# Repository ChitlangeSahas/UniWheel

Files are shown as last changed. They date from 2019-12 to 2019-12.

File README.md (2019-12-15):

# UniWheel - A DIY self balancing mobility vehicle

<p>
             
 </p>
<br>
<br>

*I built this project over 9 month time period, going from the ideation to the prototype.*

### Contains: 
* NodeMCU Controller Code (__C++__) 
* Android App Code repository (__Java__) : [link to the repository](https://github.com/ChitlangeSahas/UniWheel-Android-App) 
* CAD Files Inventor (__Inventor Professional 2019__)

### Media :
 * Video in action : [Watch Video](https://bit.ly/sahas-uniwheel)
 * CAD Render Model : 
 
    <p align="center">
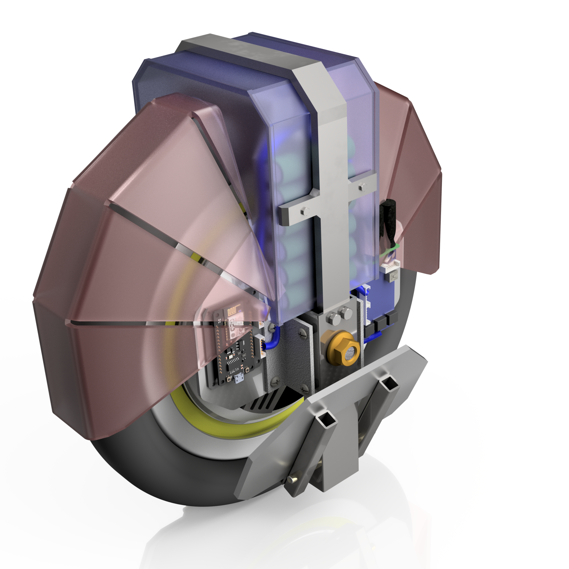
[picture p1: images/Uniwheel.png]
      
      </p>
 
### Some favorite captures :
<p align="center">
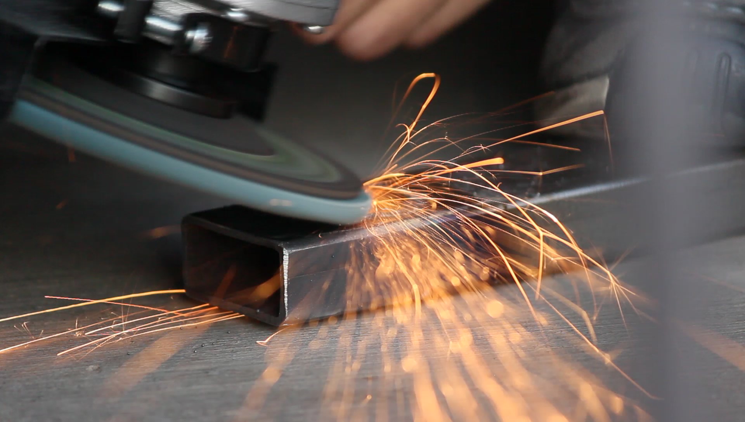
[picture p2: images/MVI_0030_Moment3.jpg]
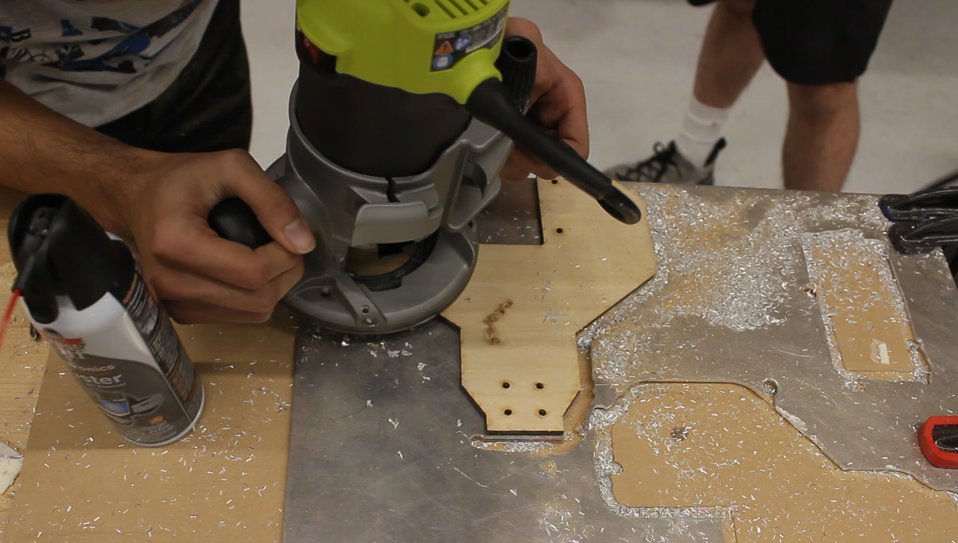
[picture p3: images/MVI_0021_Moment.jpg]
   
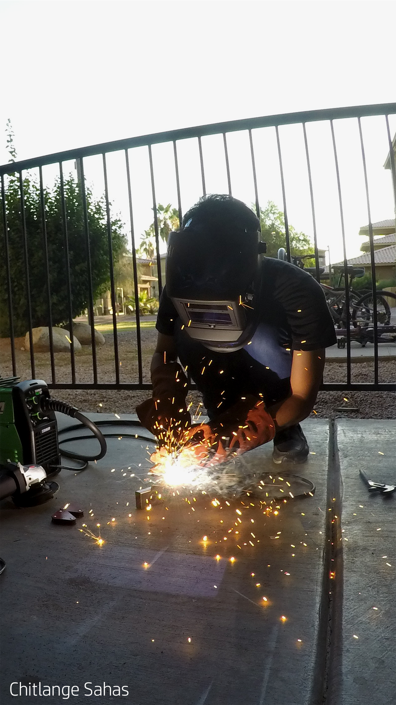
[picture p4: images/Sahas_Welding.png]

</p>

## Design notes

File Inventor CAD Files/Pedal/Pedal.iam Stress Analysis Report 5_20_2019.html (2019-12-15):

Image Width (pixels):

# Stress Analysis Report



Analyzed File: | Pedal.iam
Autodesk Inventor Version: | 2020 (Build 240168000, 168)
Creation Date: | 5/20/2019, 12:16 PM
Study Author: | chitl
Summary: | Report on Pedal Strength

###  Project Info (iProperties)

####  Summary

Author | chitl

####  Project

Part Number | Pedal
Designer | chitl
Cost | $0.00
Date Created | 5/20/2019

####  Status

Design Status | WorkInProgress

####  Physical

Mass | 1.62895 lbmass
Area | 138.184 in^2
Volume | 9.96578 in^3
Center of Gravity | x=-0.866883 in y=-0.56357 in z=0.83923 in

Note: Physical values could be different from Physical values used by FEA reported below.

##  Static Analysis:1

General objective and settings:

Design Objective | Single Point
Study Type | Static Analysis
Last Modification Date | 5/20/2019, 12:14 PM
Detect and Eliminate Rigid Body Modes | No
Separate Stresses Across Contact Surfaces | No
Motion Loads Analysis | No

Mesh settings:

Avg. Element Size (fraction of model diameter) | 0.1
Min. Element Size (fraction of avg. size) | 0.2
Grading Factor | 1.5
Max. Turn Angle | 60 deg
Create Curved Mesh Elements | No
Use part based measure for Assembly mesh | Yes

###  Material(s)

Name | Steel, Mild
General | Mass Density | 0.283599 lbmass/in^3
| Yield Strength | 30022.8 psi
| Ultimate Tensile Strength | 50038 psi
Stress | Young's Modulus | 31908.3 ksi
| Poisson's Ratio | 0.275 ul
| Shear Modulus | 12513.1 ksi
Part Name(s) | Pedal_Steel_1.5_0.75.ipt Sleeve_0.5.ipt ANSI 1/2 x 1/2 x 13/200 ANSI 1/2 x 1/2 x 13/200 ANSI 1/2 x 1/2 x 13/200

Name | Generic
General | Mass Density | 0.0361273 lbmass/in^3
| Yield Strength | 0 psi
| Ultimate Tensile Strength | 0 psi
Stress | Young's Modulus | 0.0000145038 ksi
| Poisson's Ratio | 0 ul
| Shear Modulus | 0.00000725189 ksi
Part Name(s) | Skeleton 1558256322524.ipt

Name | Aluminum 6061
General | Mass Density | 0.0975437 lbmass/in^3
| Yield Strength | 39885.4 psi
| Ultimate Tensile Strength | 44961.7 psi
Stress | Young's Modulus | 9993.1 ksi
| Poisson's Ratio | 0.33 ul
| Shear Modulus | 3756.8 ksi
Part Name(s) | Footrest_Aluminum_Top.ipt

Name | Stainless Steel
General | Mass Density | 0.289018 lbmass/in^3
| Yield Strength | 36259.4 psi
| Ultimate Tensile Strength | 78320.4 psi
Stress | Young's Modulus | 27992.3 ksi
| Poisson's Ratio | 0.3 ul
| Shear Modulus | 10766.3 ksi
Part Name(s) | Axle.ipt

###  Operating conditions

####  Force:1

Load Type | Force
Magnitude | 500.000 lbforce
Vector X | 6.252 lbforce
Vector Y | -499.961 lbforce
Vector Z | -0.000 lbforce

#####  Selected Face(s)

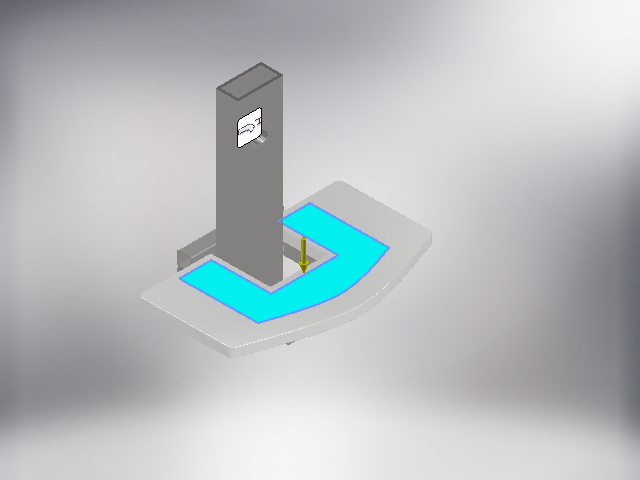
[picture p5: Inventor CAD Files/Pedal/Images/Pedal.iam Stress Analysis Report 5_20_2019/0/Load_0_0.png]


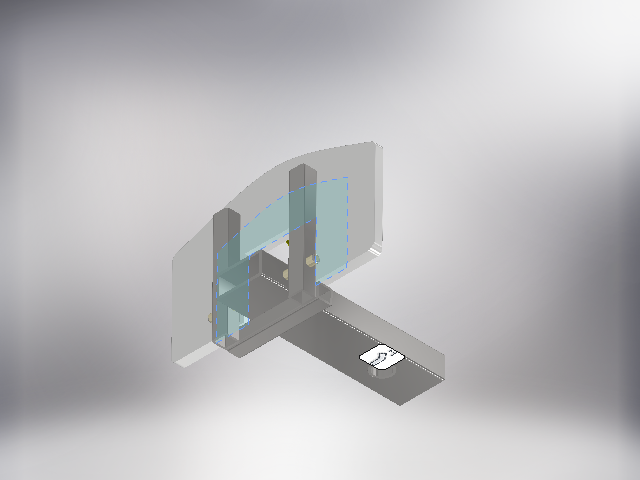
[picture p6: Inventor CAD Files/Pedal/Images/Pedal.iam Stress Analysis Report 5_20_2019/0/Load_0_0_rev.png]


####  Fixed Constraint:1

Constraint Type | Fixed Constraint

#####  Selected Face(s)

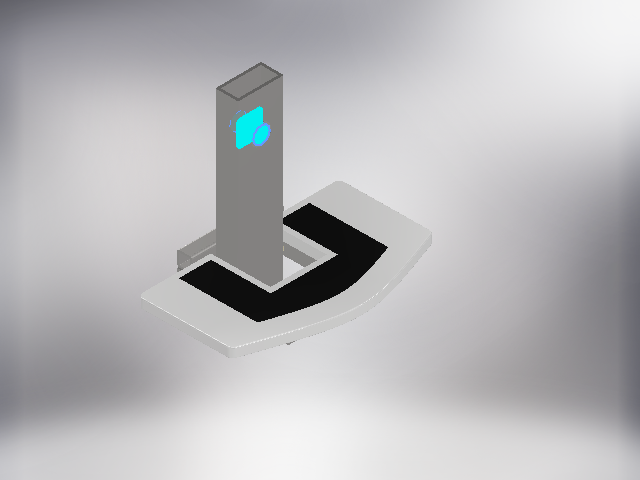
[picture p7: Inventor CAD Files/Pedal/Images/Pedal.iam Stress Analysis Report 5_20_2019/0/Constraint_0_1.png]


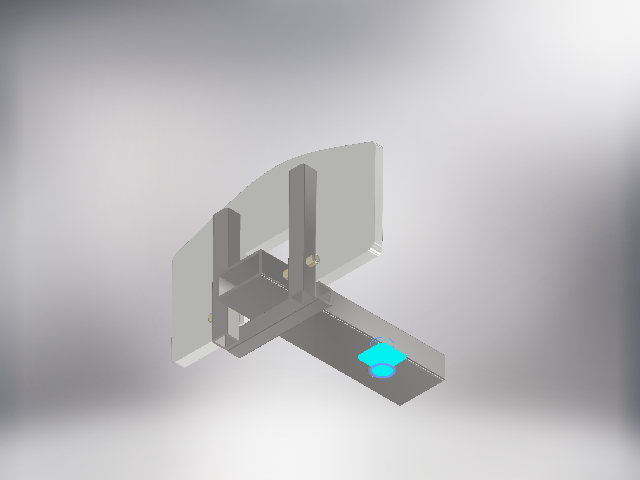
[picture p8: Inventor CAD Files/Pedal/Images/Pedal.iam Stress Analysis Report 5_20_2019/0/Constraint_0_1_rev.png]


####  Contacts (Bonded)

Name | Part Name(s)
Bonded:1 | Pedal_tube:1/Pedal_Steel_1.5_0.75:1 Pedal_tube:1/Pedal_Steel_1.5_0.75:1
Bonded:2 | Pedal_tube:1/Pedal_Steel_1.5_0.75:1 Pedal_tube:1/Pedal_Steel_1.5_0.75:1
Bonded:3 | Pedal_tube:1/Pedal_Steel_1.5_0.75:1 Pedal_tube:1/Sleeve_0.5:1
Bonded:4 | Pedal_tube:1/Pedal_Steel_1.5_0.75:1 Axle:1
Bonded:5 | Pedal_tube:1/Pedal_Steel_1.5_0.75:1 Axle:1
Bonded:6 | Pedal_tube:1/Pedal_Steel_1.5_0.75:1 Footrest:1/Frame 1558256322523:1/ANSI 1/2 x 1/2 x 13/200:3
Bonded:7 | Pedal_tube:1/Pedal_Steel_1.5_0.75:1 Pedal_tube:1/Sleeve_0.5:1
Bonded:8 | Footrest:1/Frame 1558256322523:1/ANSI 1/2 x 1/2 x 13/200:3 Footrest:1/Footrest_Aluminum_Top:1
Bonded:9 | Footrest:1/Frame 1558256322523:1/ANSI 1/2 x 1/2 x 13/200:3 Footrest:1/Footrest_Aluminum_Top:1
Bonded:10 | Footrest:1/Frame 1558256322523:1/ANSI 1/2 x 1/2 x 13/200:2 Footrest:1/Frame 1558256322523:1/ANSI 1/2 x 1/2 x 13/200:3
Bonded:11 | Footrest:1/Frame 1558256322523:1/ANSI 1/2 x 1/2 x 13/200:2 Footrest:1/Footrest_Aluminum_Top:1
Bonded:12 | Footrest:1/Frame 1558256322523:1/ANSI 1/2 x 1/2 x 13/200:2 Axle:1
Bonded:13 | Footrest:1/Frame 1558256322523:1/ANSI 1/2 x 1/2 x 13/200:2 Axle:1
Bonded:14 | Footrest:1/Frame 1558256322523:1/ANSI 1/2 x 1/2 x 13/200:1 Footrest:1/Frame 1558256322523:1/ANSI 1/2 x 1/2 x 13/200:3
Bonded:15 | Footrest:1/Frame 1558256322523:1/ANSI 1/2 x 1/2 x 13/200:1 Footrest:1/Footrest_Aluminum_Top:1
Bonded:16 | Footrest:1/Frame 1558256322523:1/ANSI 1/2 x 1/2 x 13/200:1 Axle:1
Bonded:17 | Footrest:1/Frame 1558256322523:1/ANSI 1/2 x 1/2 x 13/200:1 Axle:1

###  Results

####  Reaction Force and Moment on Constraints

Constraint Name | Reaction Force | | Reaction Moment
| Magnitude | Component (X,Y,Z) | Magnitude | Component (X,Y,Z)
Fixed Constraint:1 | 500 lbforce | -6.25169 lbforce | 58.0095 lbforce ft | 0.54768 lbforce ft
| | 499.961 lbforce | | 0 lbforce ft
| | 0 lbforce | | 58.007 lbforce ft

####  Result Summary

Name | Minimum | Maximum
Volume | 9.96597 in^3
Mass | 1.62897 lbmass
Von Mises Stress | 0.00332243 ksi | 82.5656 ksi
1st Principal Stress | -28.3835 ksi | 113.418 ksi
3rd Principal Stress | -93.0376 ksi | 26.3998 ksi
Displacement | 0 in | 0.0273657 in
Safety Factor | 0.363624 ul | 15 ul
Stress XX | -51.9869 ksi | 54.7235 ksi
Stress XY | -26.3637 ksi | 28.1427 ksi
Stress XZ | -27.3286 ksi | 25.3903 ksi
Stress YY | -67.6294 ksi | 73.9498 ksi
Stress YZ | -32.0055 ksi | 34.4498 ksi
Stress ZZ | -73.4698 ksi | 57.6751 ksi
X Displacement | -0.00811705 in | 0.000210778 in
Y Displacement | -0.0270654 in | 0.00394208 in
Z Displacement | -0.000461852 in | 0.00052754 in
Equivalent Strain | 0.0000000934193 ul | 0.0024913 ul
1st Principal Strain | -0.0000435546 ul | 0.0030152 ul
3rd Principal Strain | -0.00273536 ul | 0.0000114153 ul
Strain XX | -0.00146212 ul | 0.00127201 ul
Strain XY | -0.00105345 ul | 0.00112453 ul
Strain XZ | -0.00126918 ul | 0.00117916 ul
Strain YY | -0.00171578 ul | 0.00186218 ul
Strain YZ | -0.00144372 ul | 0.00153983 ul
Strain ZZ | -0.00202374 ul | 0.00142439 ul
Contact Pressure | 0 ksi | 138.266 ksi
Contact Pressure X | -74.331 ksi | 63.9325 ksi
Contact Pressure Y | -115.047 ksi | 64.4322 ksi
Contact Pressure Z | -62.586 ksi | 74.2969 ksi

####  Figures

#####  Von Mises Stress

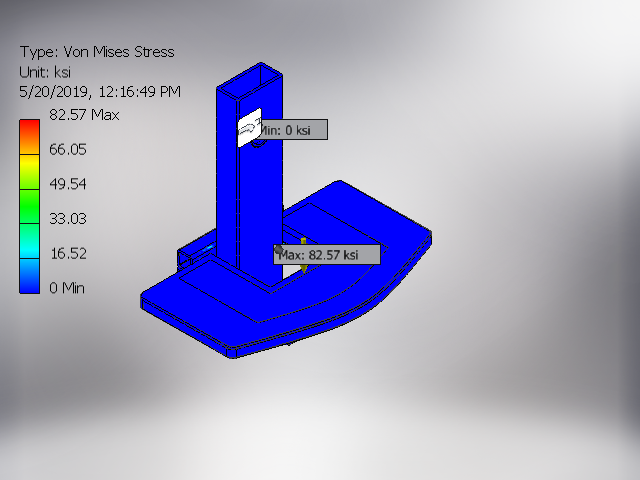
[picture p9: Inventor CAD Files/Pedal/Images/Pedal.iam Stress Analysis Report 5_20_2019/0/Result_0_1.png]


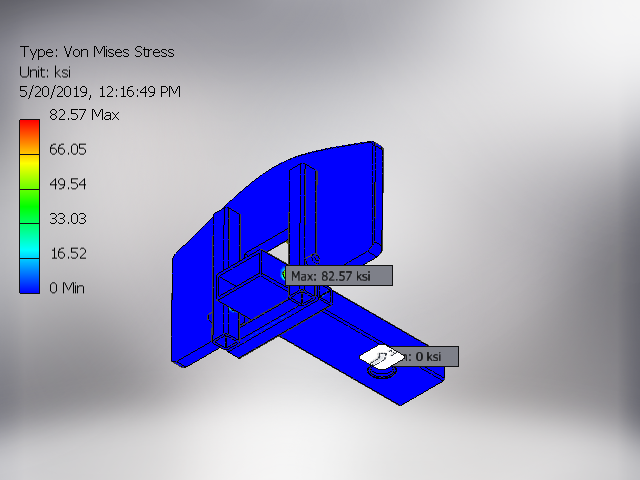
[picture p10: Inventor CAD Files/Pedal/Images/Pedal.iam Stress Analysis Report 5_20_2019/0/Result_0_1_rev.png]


#####  1st Principal Stress

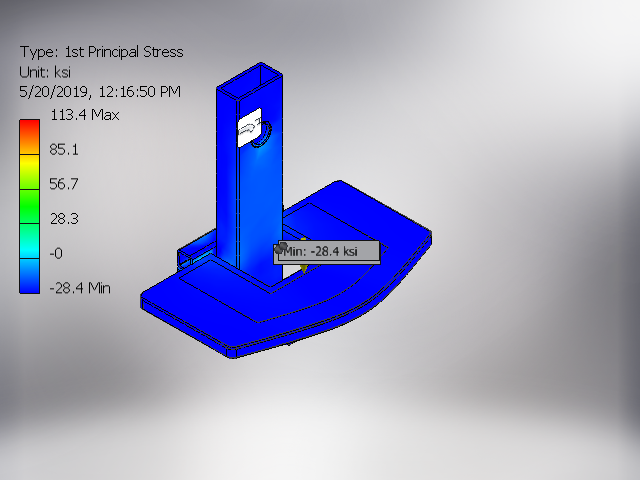
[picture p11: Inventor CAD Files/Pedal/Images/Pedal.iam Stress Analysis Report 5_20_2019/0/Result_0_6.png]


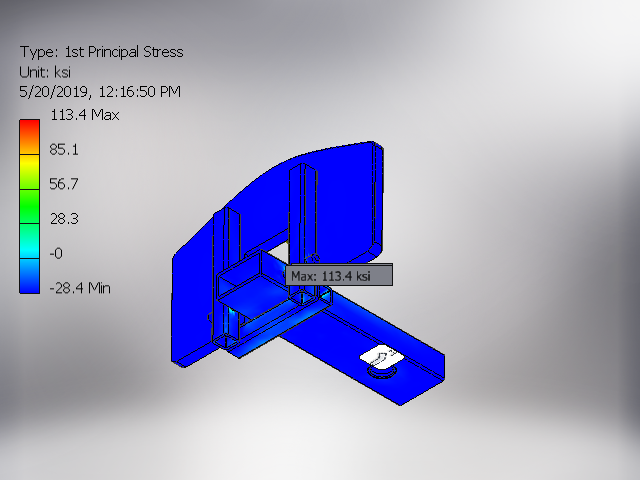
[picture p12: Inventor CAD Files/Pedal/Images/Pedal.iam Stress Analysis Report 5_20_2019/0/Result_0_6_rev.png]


#####  3rd Principal Stress

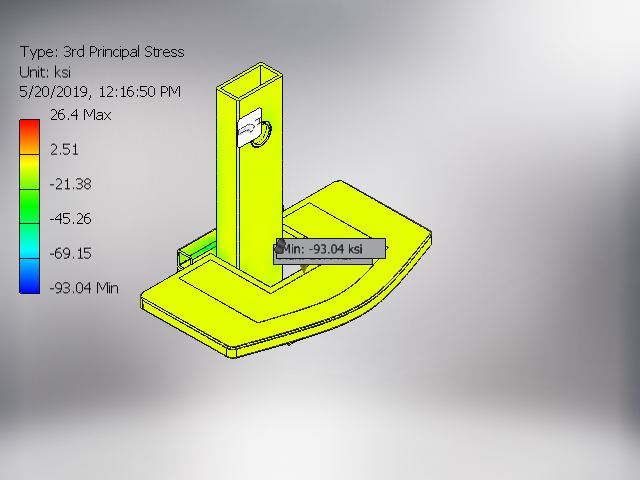
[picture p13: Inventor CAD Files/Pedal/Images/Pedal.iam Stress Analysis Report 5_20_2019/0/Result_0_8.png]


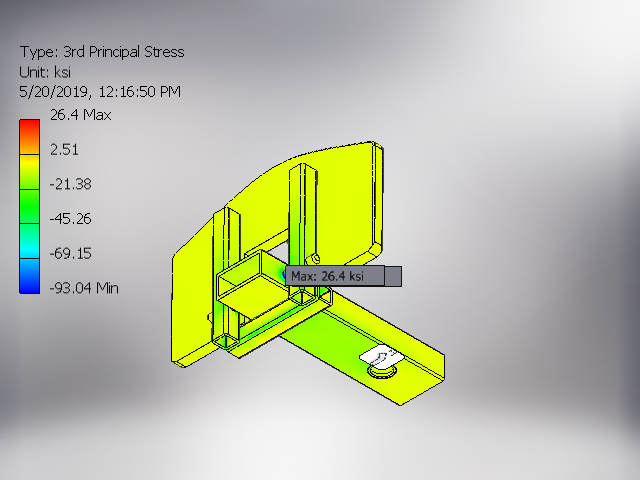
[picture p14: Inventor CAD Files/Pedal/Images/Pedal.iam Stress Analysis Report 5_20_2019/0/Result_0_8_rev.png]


#####  Displacement

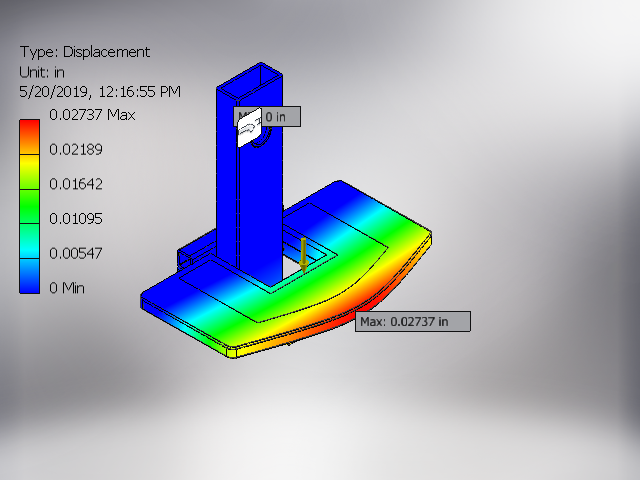
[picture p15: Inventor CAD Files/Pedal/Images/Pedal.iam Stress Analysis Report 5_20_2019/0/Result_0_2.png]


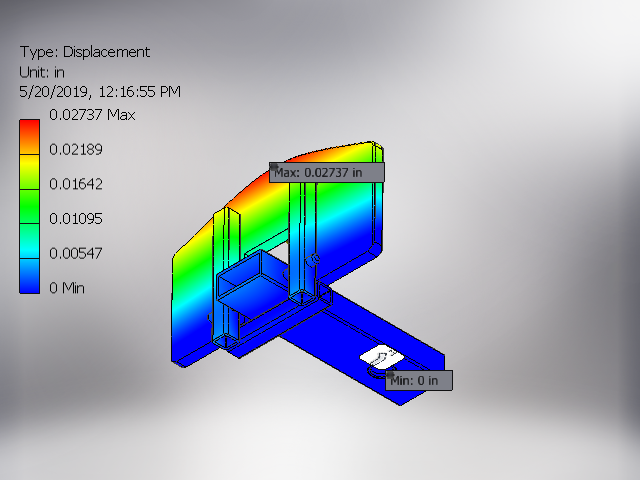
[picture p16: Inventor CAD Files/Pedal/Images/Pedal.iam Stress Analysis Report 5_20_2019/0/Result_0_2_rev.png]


#####  Safety Factor

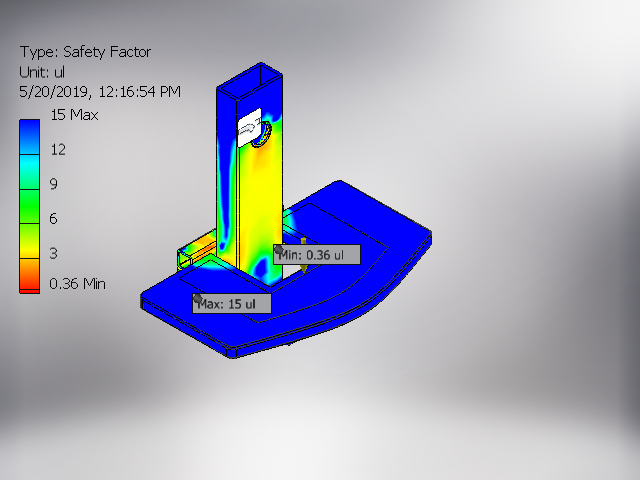
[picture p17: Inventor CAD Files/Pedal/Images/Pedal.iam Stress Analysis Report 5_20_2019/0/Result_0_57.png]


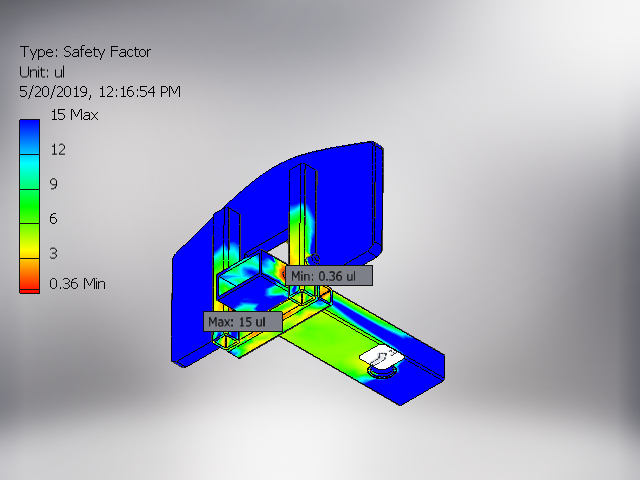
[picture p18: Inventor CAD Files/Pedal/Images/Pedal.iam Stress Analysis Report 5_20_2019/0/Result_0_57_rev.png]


#####  Stress XX

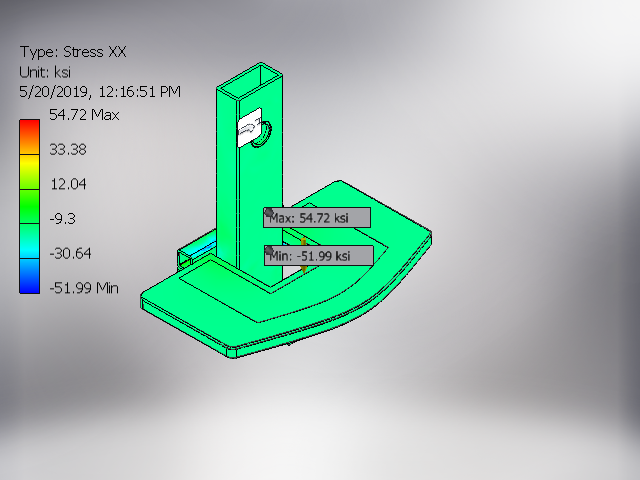
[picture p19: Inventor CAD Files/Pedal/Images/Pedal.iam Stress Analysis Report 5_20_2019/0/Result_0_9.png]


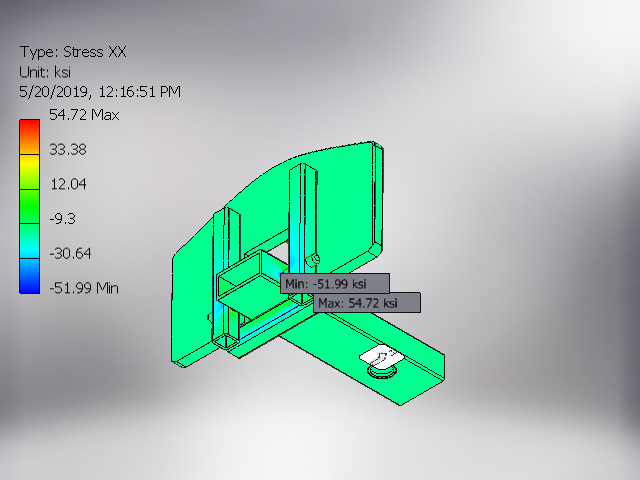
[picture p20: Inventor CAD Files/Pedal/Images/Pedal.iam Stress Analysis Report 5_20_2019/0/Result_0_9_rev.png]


#####  Stress XY

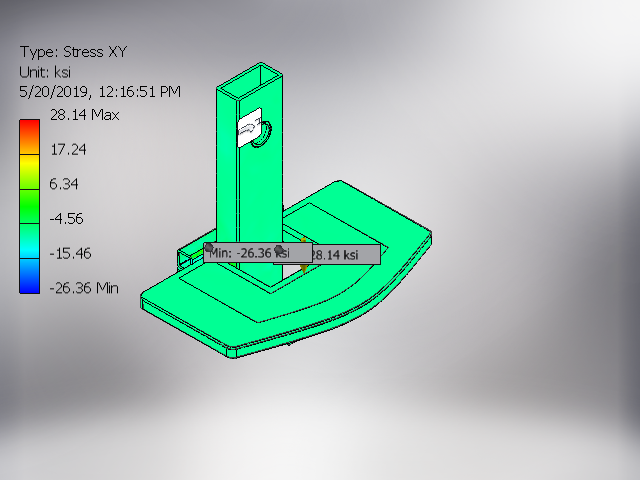
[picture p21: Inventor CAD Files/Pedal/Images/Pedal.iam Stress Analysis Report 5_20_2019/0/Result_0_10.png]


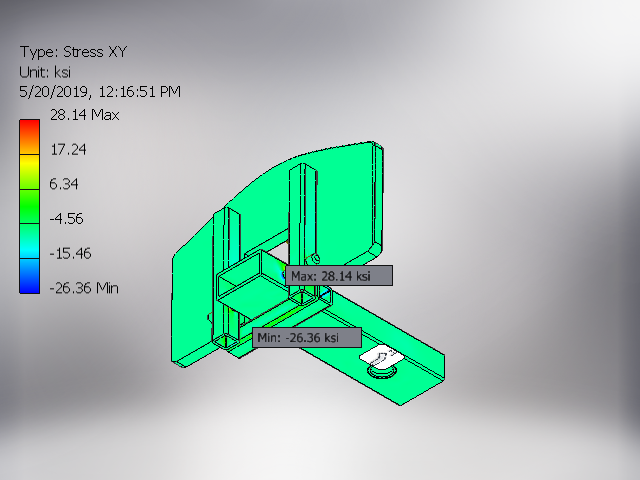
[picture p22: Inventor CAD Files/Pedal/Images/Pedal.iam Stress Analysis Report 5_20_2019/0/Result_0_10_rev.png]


#####  Stress XZ

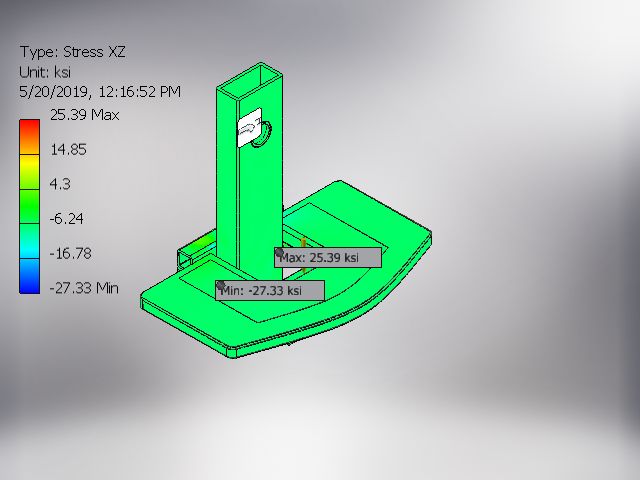
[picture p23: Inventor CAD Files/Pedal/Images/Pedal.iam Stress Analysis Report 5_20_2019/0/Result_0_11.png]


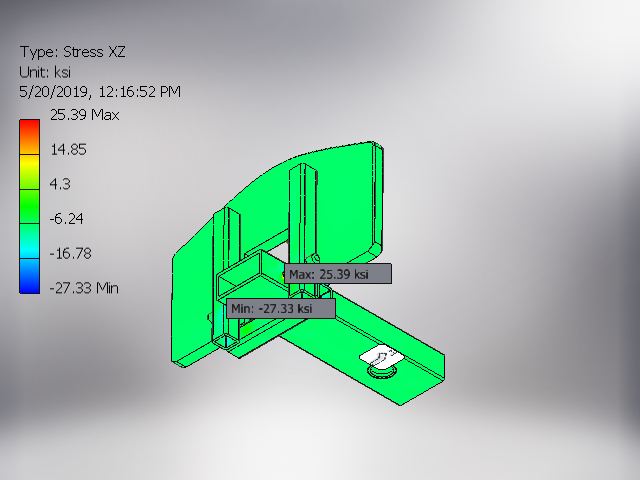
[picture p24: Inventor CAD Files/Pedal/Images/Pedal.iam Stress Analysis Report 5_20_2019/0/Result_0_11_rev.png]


#####  Stress YY

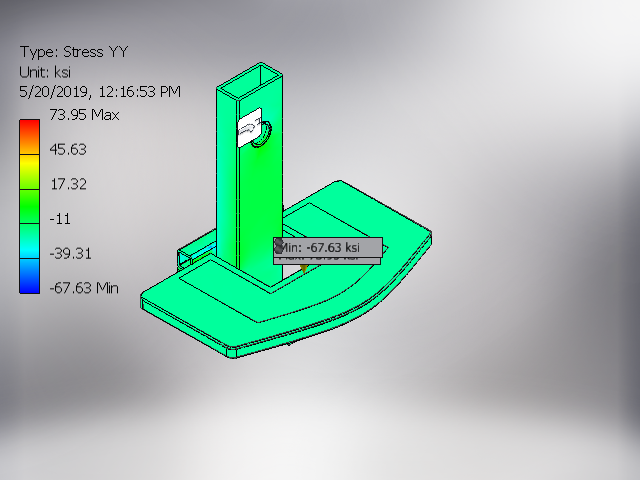
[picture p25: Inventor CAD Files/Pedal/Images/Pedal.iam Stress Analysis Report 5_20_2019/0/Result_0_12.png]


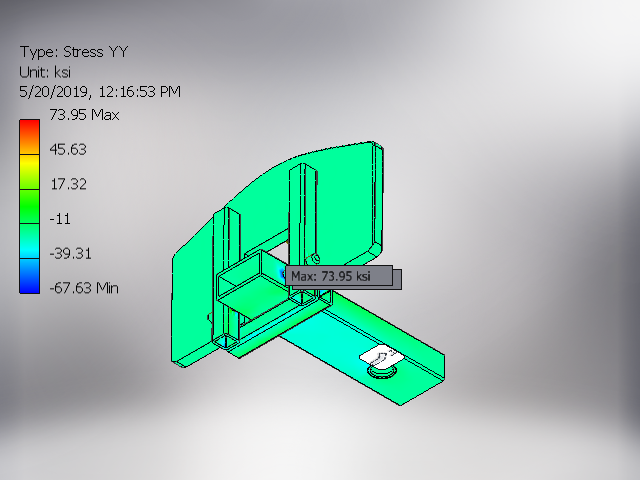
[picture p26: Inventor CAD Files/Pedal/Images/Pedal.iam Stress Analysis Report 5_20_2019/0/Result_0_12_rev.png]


#####  Stress YZ

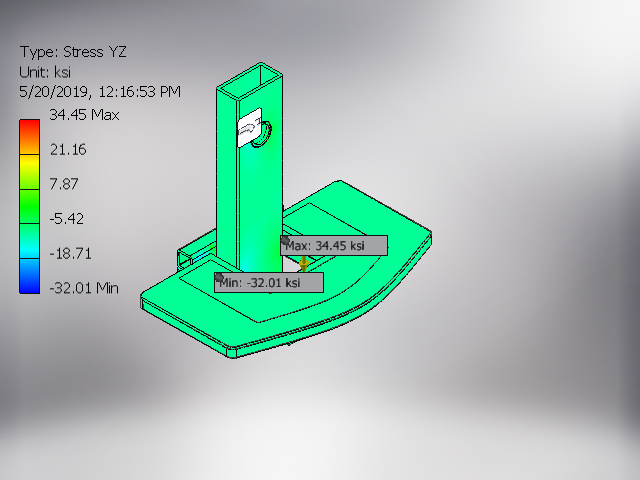
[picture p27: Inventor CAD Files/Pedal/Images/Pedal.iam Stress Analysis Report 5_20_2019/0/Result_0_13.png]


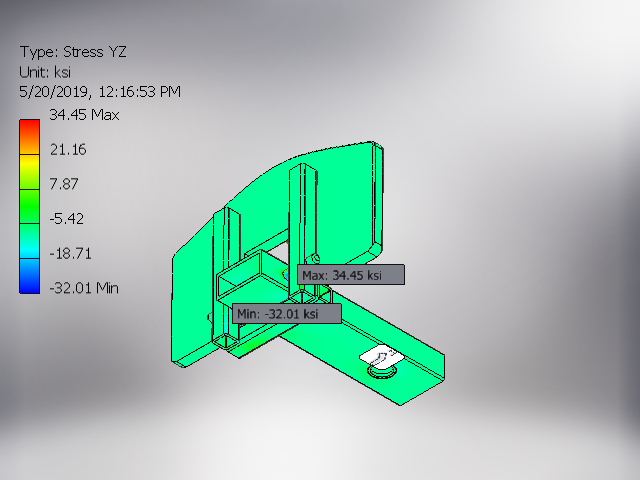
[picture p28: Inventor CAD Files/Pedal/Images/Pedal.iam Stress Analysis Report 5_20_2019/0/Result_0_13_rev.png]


#####  Stress ZZ





#####  X Displacement





#####  Y Displacement





#####  Z Displacement





#####  Equivalent Strain





#####  1st Principal Strain





#####  3rd Principal Strain





#####  Strain XX





#####  Strain XY





#####  Strain XZ





#####  Strain YY





#####  Strain YZ





#####  Strain ZZ





#####  Contact Pressure





#####  Contact Pressure X





#####  Contact Pressure Y





#####  Contact Pressure Z





C:\Users\chitl\Desktop\OneWheel\Wheel Assembled\Pedal\Pedal.iam

Image Width (pixels):


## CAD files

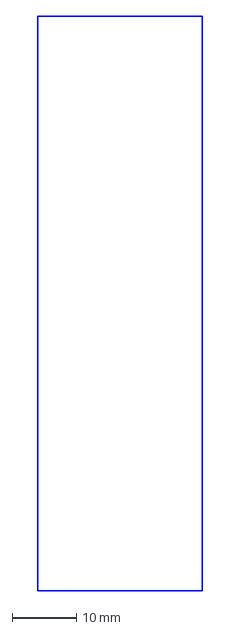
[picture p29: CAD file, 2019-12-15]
Inventor CAD Files/Battery Cover/Battery Cover v1 - Side3.dxf
25.5 x 89.1 mm

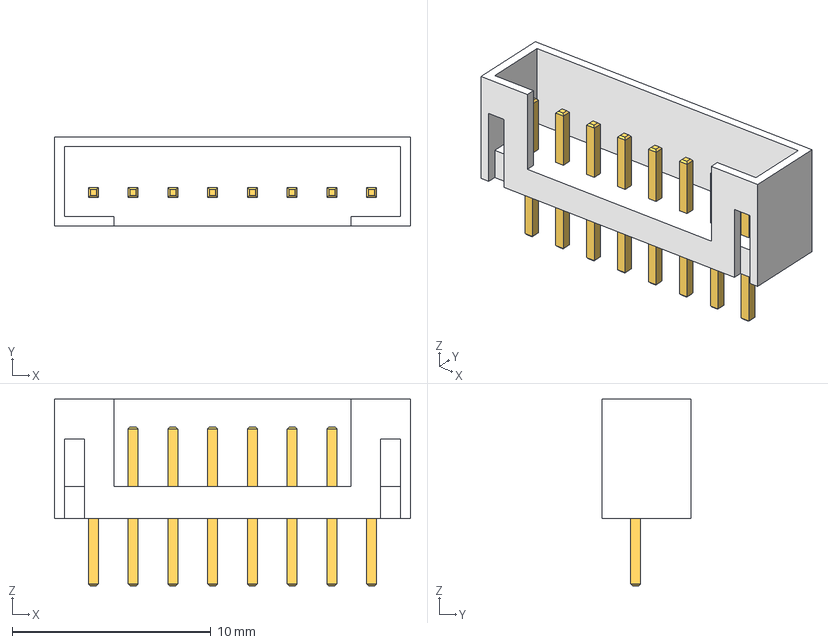
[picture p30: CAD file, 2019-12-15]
Inventor CAD Files/Electronics/JST Socket 8 Pin.step
17.9 x 4.50 x 9.40 mm

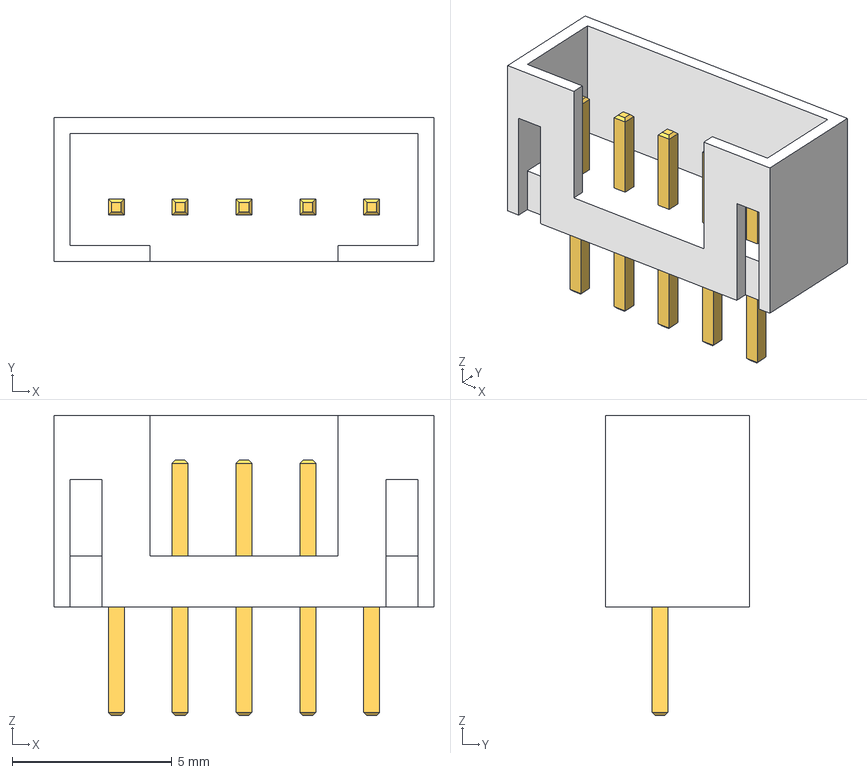
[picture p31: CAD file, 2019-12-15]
Inventor CAD Files/Electronics/jst-ph-sockets-3-to-10-pins-1.snapshot.3/JST Socket 5 Pin.step
11.9 x 4.50 x 9.40 mm

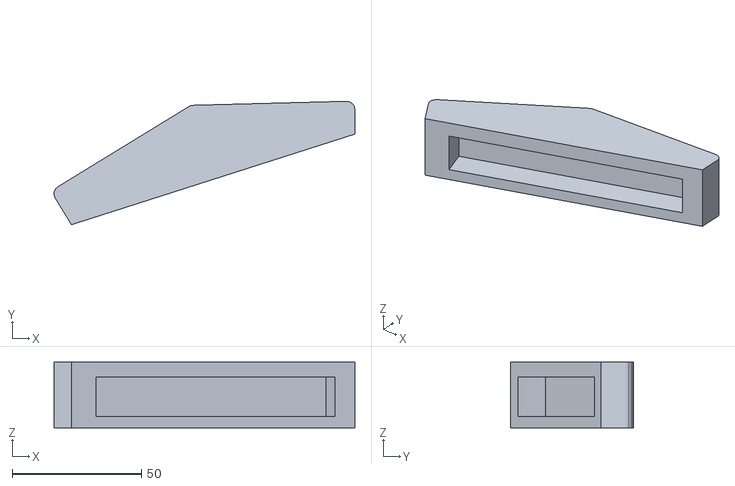
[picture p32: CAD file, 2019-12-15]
Inventor CAD Files/Fender/Part2.stl
116.4 x 47.7 x 25.4

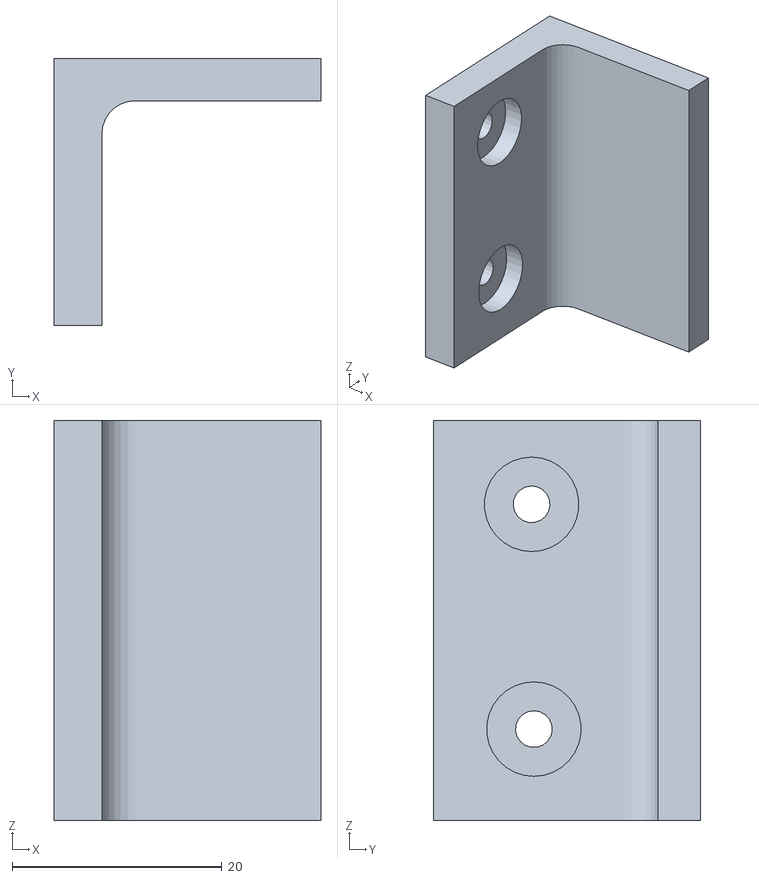
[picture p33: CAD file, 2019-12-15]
Inventor CAD Files/Gyro mount.stl
25.4 x 25.4 x 38.1

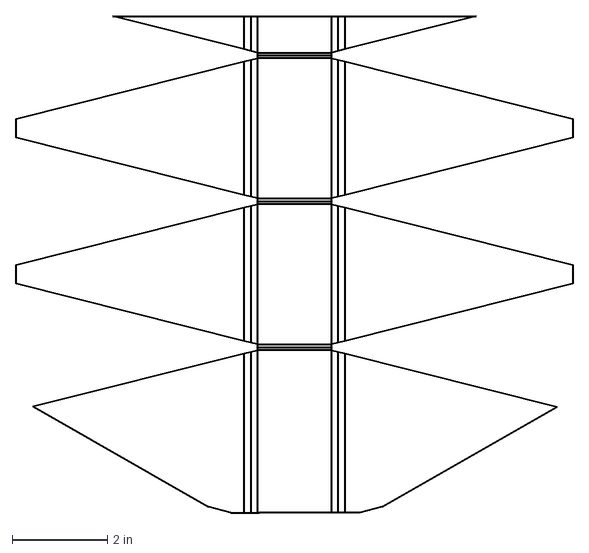
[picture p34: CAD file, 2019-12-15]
Inventor CAD Files/Sheet Metal Shell/Sheet_Metal_Template.dxf
11.7 x 10.4 in

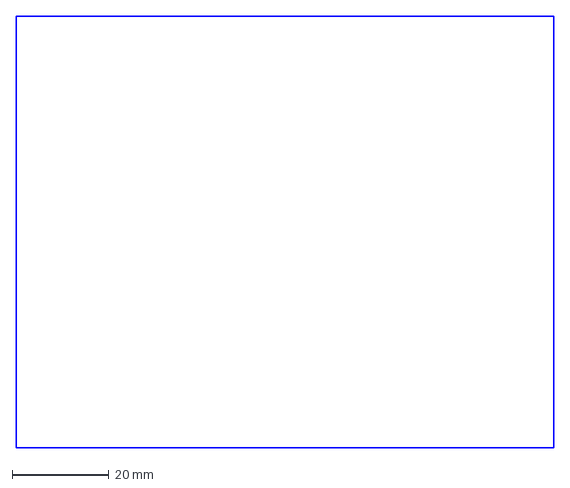
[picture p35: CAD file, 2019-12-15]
Inventor CAD Files/Battery Cover/Battery Cover v1 - Side4.dxf
110.9 x 89.1 mm

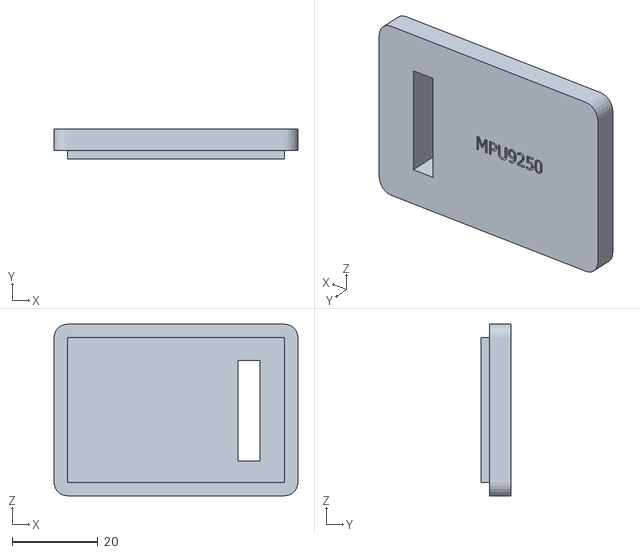
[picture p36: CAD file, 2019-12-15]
Inventor CAD Files/Electronics/Gyro_box_Top.stl
57.0 x 7.00 x 40.1

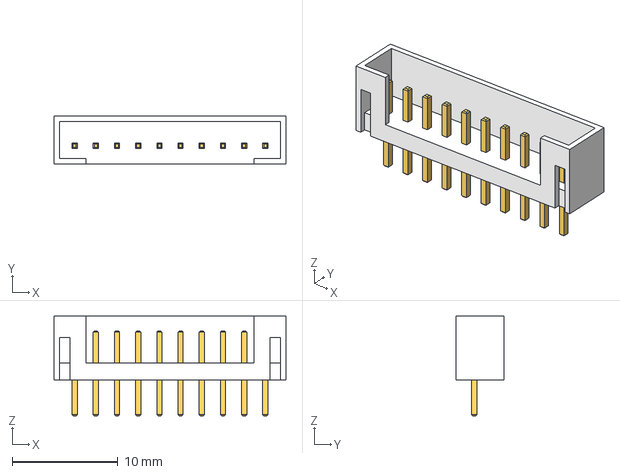
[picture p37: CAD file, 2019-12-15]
Inventor CAD Files/Electronics/jst-ph-sockets-3-to-10-pins-1.snapshot.3/JST Socket 10 Pin.step
21.9 x 4.50 x 9.40 mm

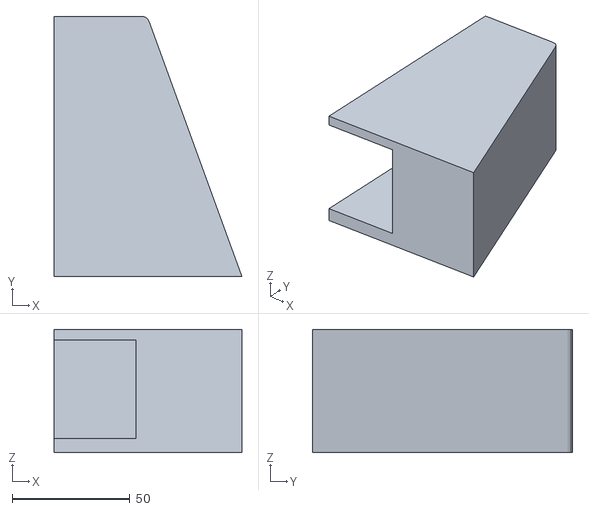
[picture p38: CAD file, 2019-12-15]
Inventor CAD Files/Fender/Support Bender.stl
79.8 x 110.5 x 52.4

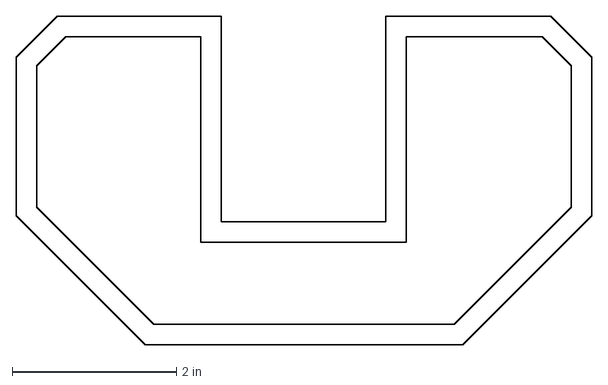
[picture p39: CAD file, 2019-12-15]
Inventor CAD Files/Pedal/Footrest/grip_tape.dxf
7.00 x 4.00 in

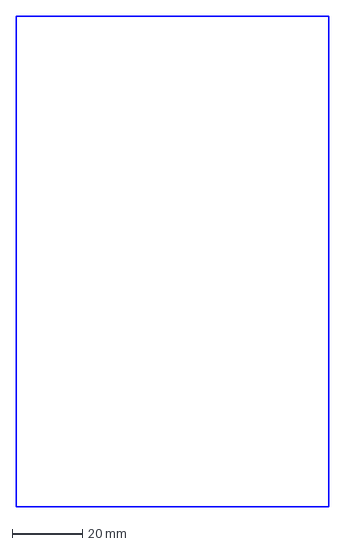
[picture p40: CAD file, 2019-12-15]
Inventor CAD Files/Battery Cover/Battery Cover v1 - Side2.dxf
89.1 x 139.9 mm

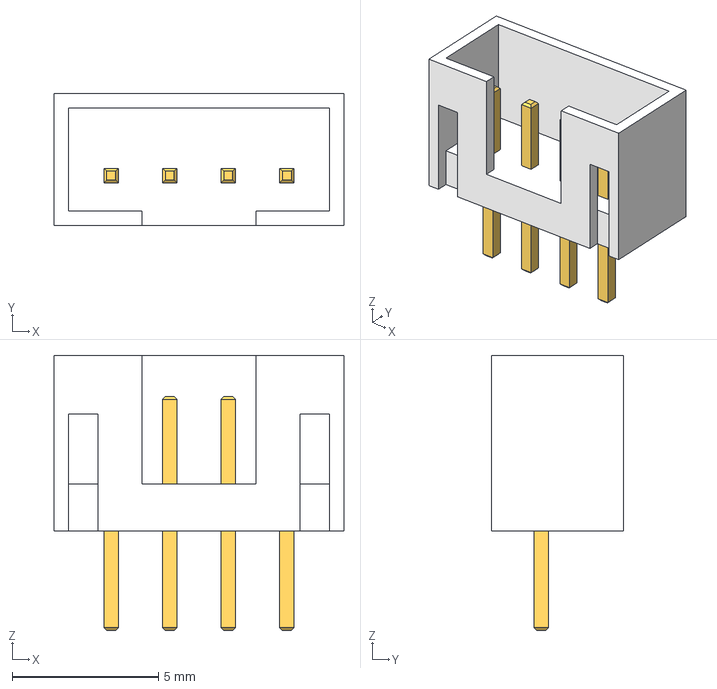
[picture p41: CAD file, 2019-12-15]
Inventor CAD Files/Electronics/JST Socket 4 Pin.step
9.90 x 4.50 x 9.40 mm

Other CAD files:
Inventor CAD Files/Pedal/Footrest/Pedal.dwg
Inventor CAD Files/Pedal/Pedal_Steel_1.5_0.75.dwg
Inventor CAD Files/Pedal/Vertical Tube/Pedal_tube-1.dwg
Inventor CAD Files/Sheet Metal Shell/Template.dwg
Inventor CAD Files/Battery Cover/Battery Cover (3).ipt
Inventor CAD Files/Battery Cover/Battery Cover v1 - Side.dxf
Inventor CAD Files/Battery Cover/Battery Cover.ipt
Inventor CAD Files/Battery Cover/OldVersions/Battery Cover (3).0007.ipt
Inventor CAD Files/Battery Cover/OldVersions/Battery Cover.0023.ipt
Inventor CAD Files/Battery Cover/OldVersions/Shell.0004.ipt
Inventor CAD Files/Battery Cover/OldVersions/Solid1.0005.ipt
Inventor CAD Files/Battery Cover/Shell.ipt
Inventor CAD Files/Battery Cover/Shell.step
Inventor CAD Files/Battery Cover/Solid1.dxf
Inventor CAD Files/Battery Cover/Solid1.ipt
Inventor CAD Files/Chassis/Chassis.iam
Inventor CAD Files/Chassis/Chassis.ipt
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

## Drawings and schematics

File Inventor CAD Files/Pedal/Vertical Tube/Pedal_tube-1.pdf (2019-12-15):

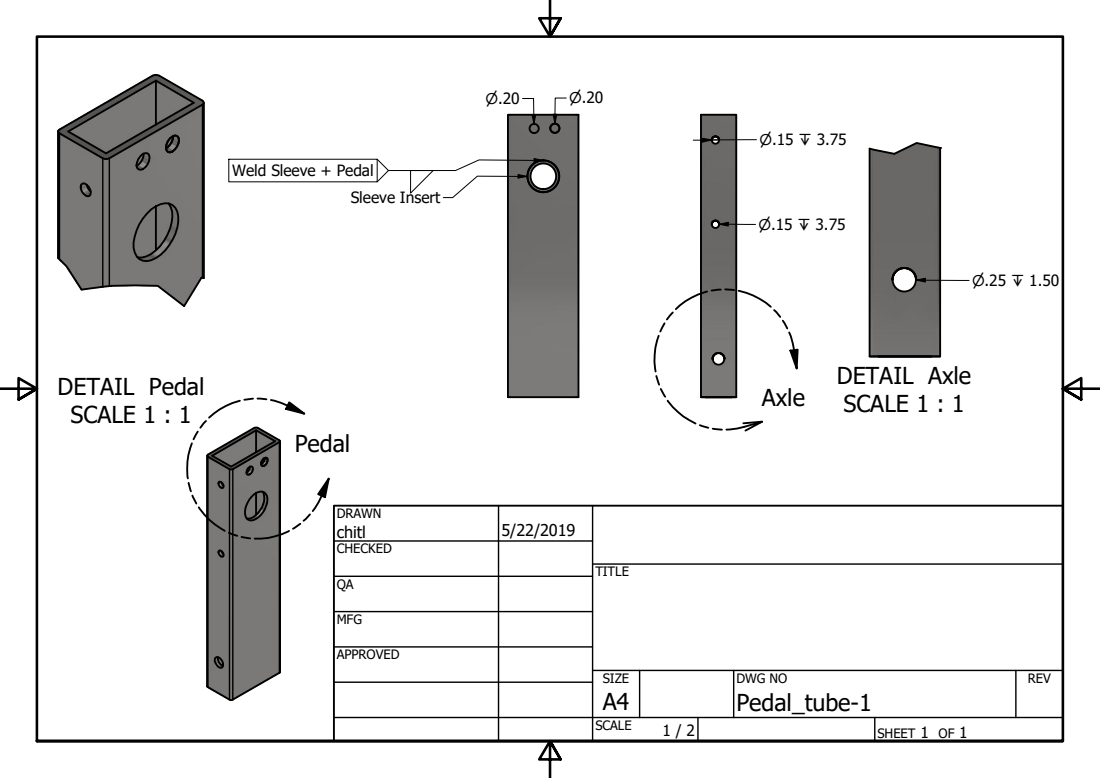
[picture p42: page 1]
DETAIL Axle SCALE 1 : 1; DETAIL Pedal SCALE 1 : 1; Sleeve Insert

Weld Sleeve + Pedal

DRAWN chitl | 5/22/2019

CHECKED

MFG

APPROVED

SIZE A4 | DWG NO Pedal_tube-1 | REV

SCALE 1 / 2 | | SHEET 1 OF 1

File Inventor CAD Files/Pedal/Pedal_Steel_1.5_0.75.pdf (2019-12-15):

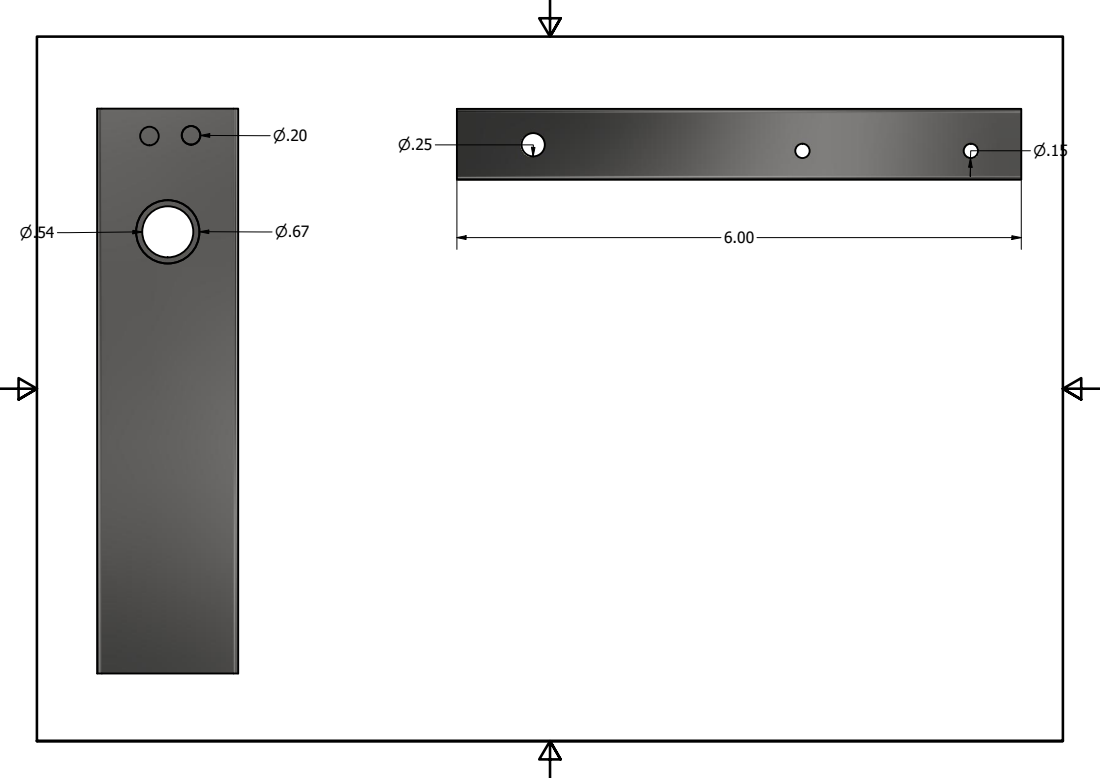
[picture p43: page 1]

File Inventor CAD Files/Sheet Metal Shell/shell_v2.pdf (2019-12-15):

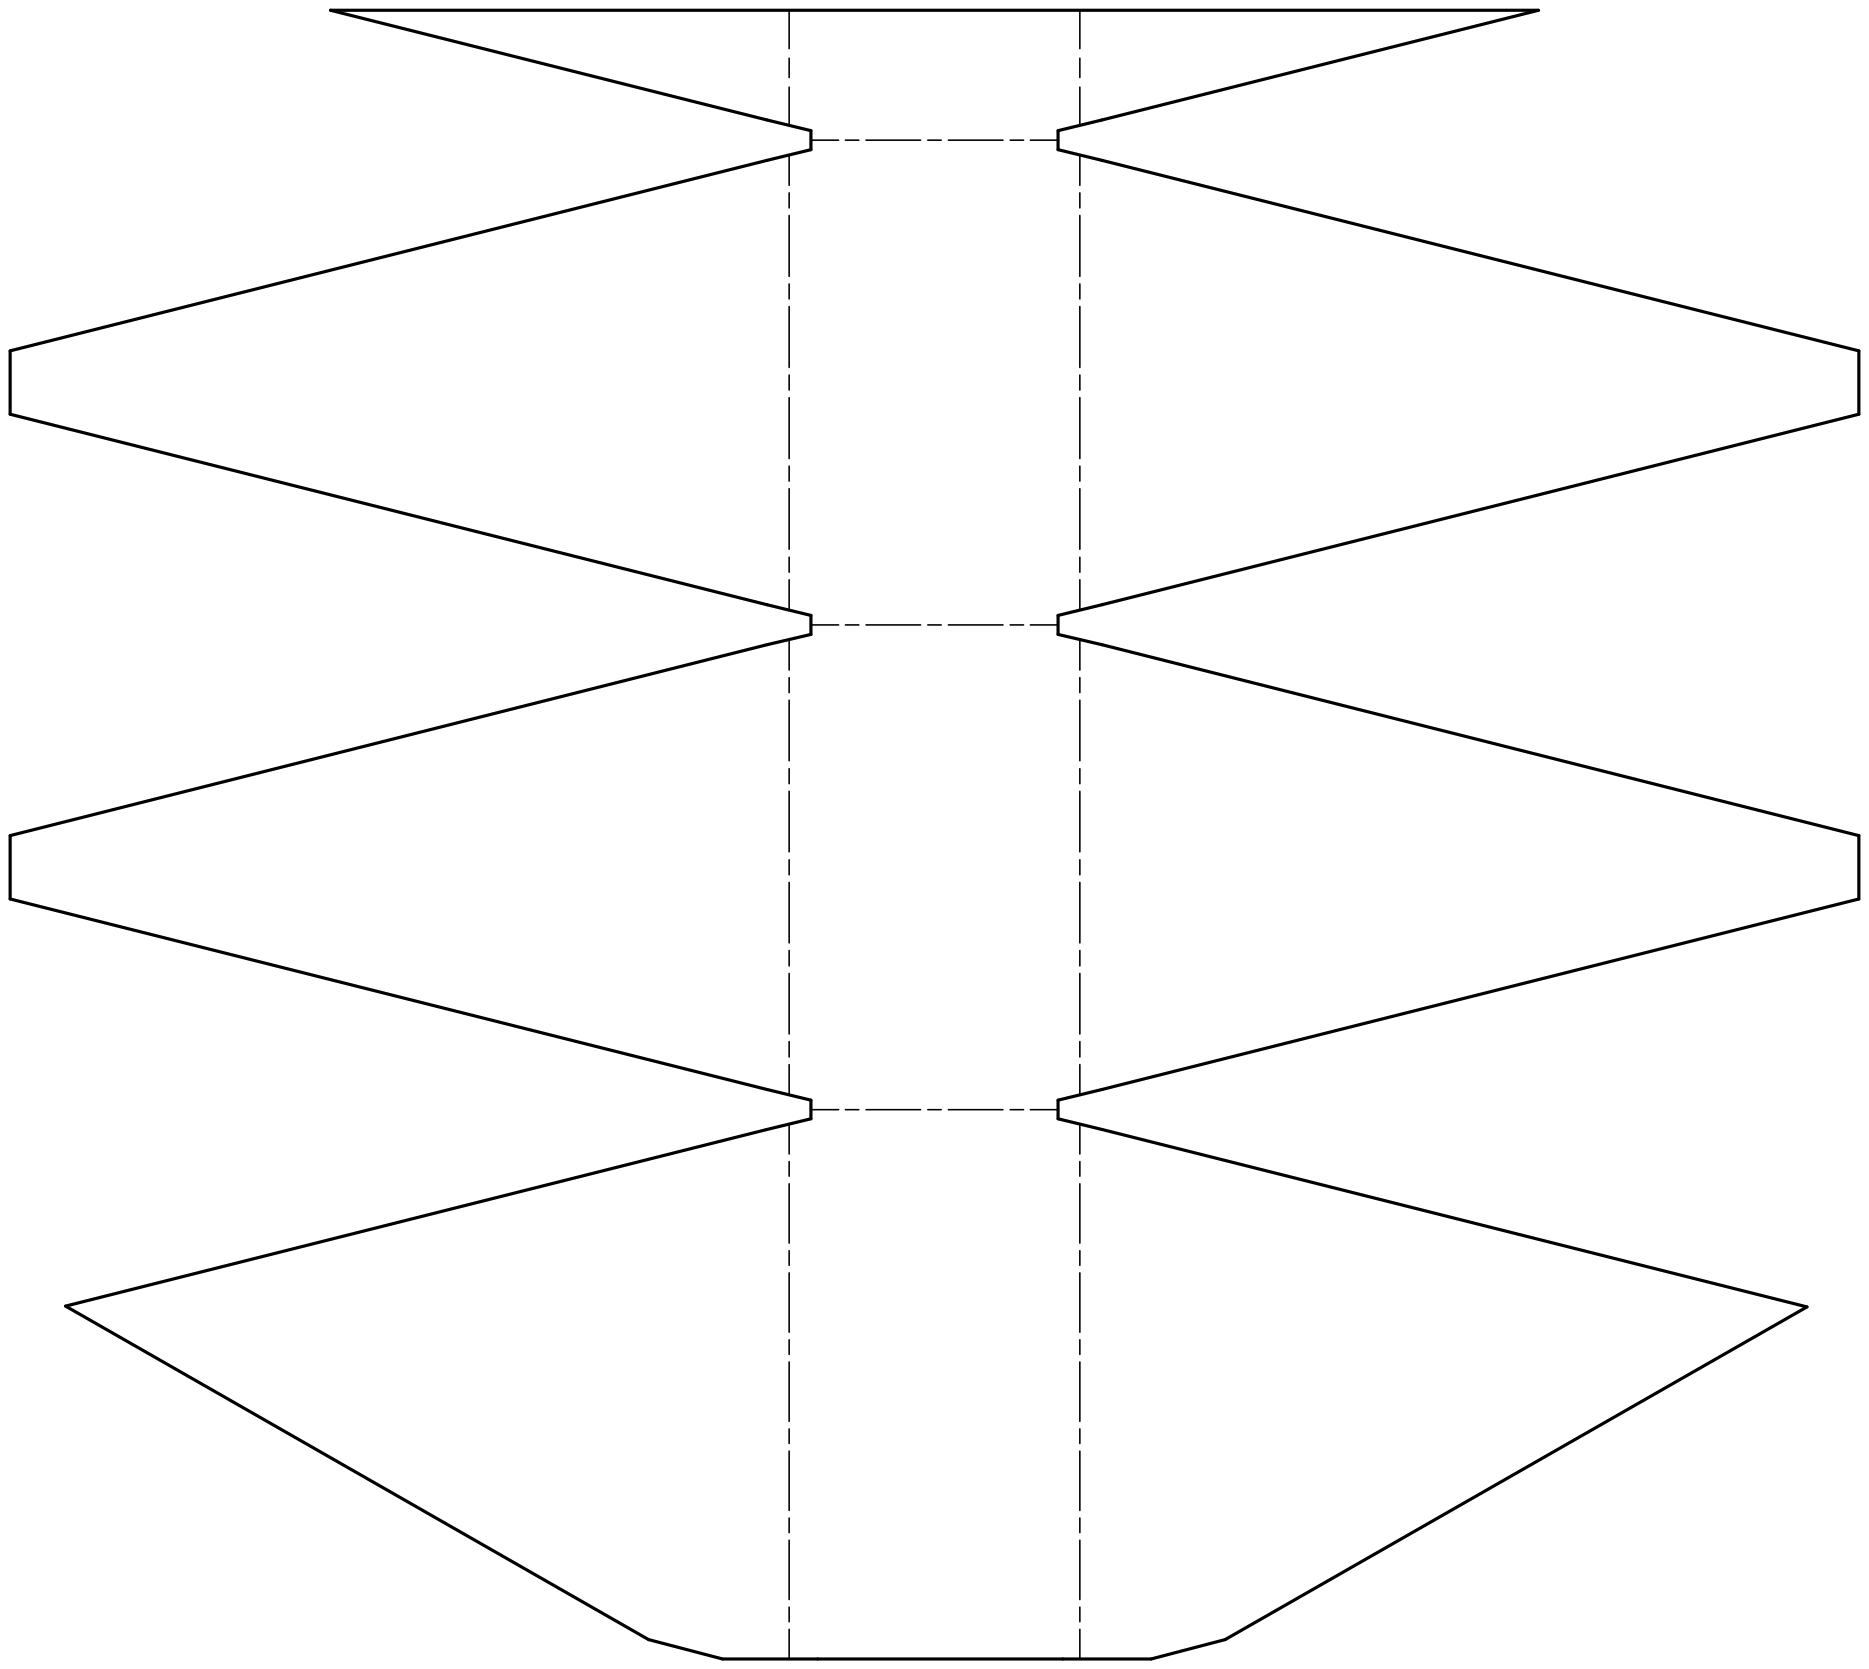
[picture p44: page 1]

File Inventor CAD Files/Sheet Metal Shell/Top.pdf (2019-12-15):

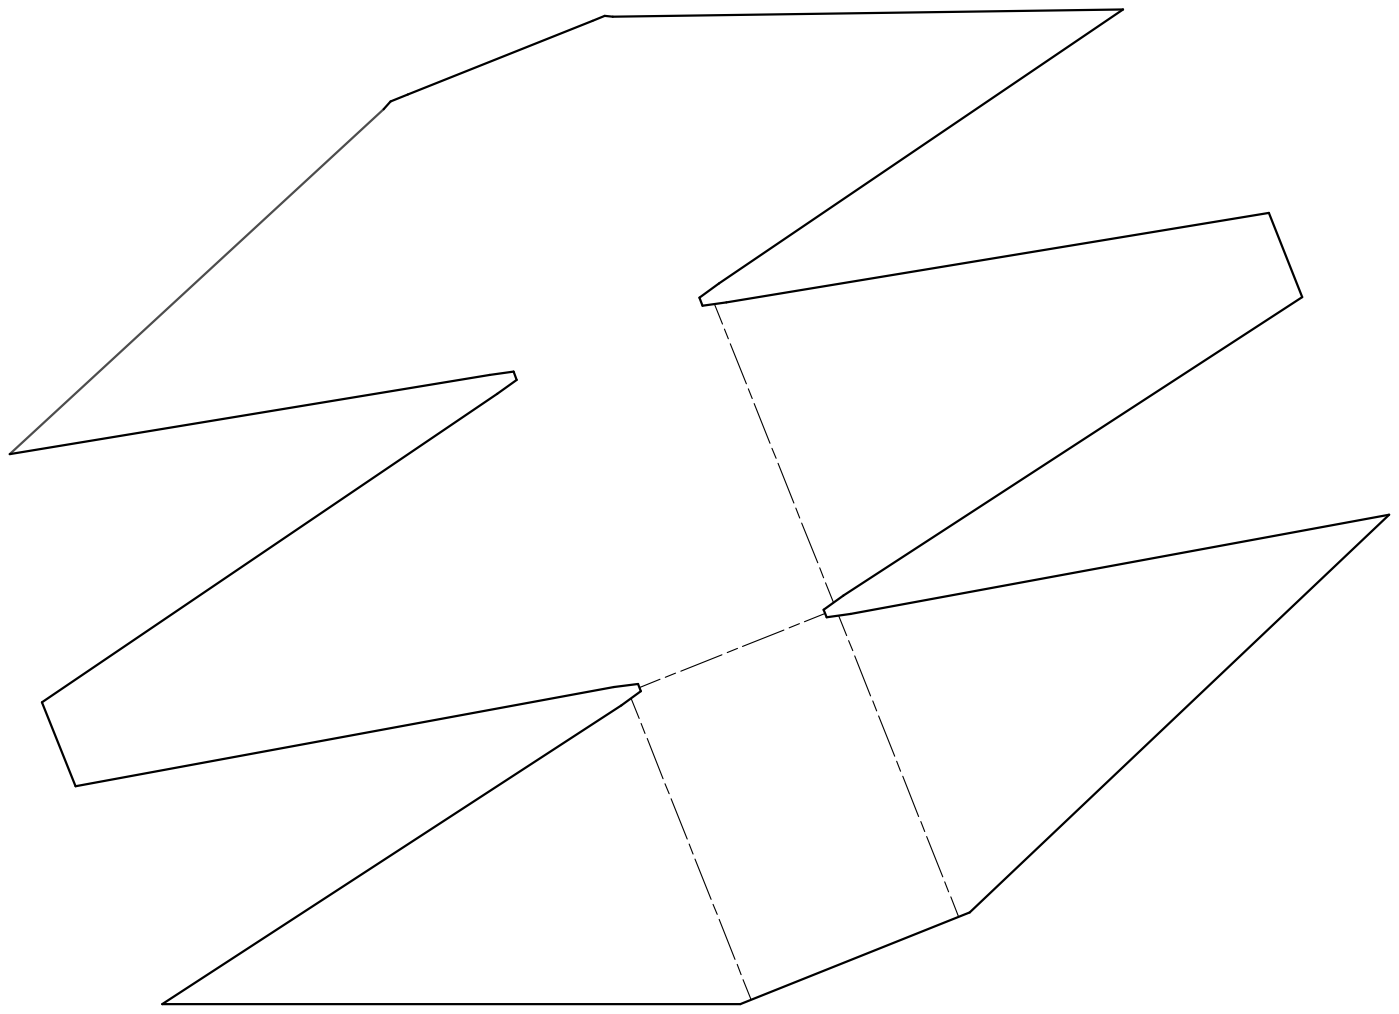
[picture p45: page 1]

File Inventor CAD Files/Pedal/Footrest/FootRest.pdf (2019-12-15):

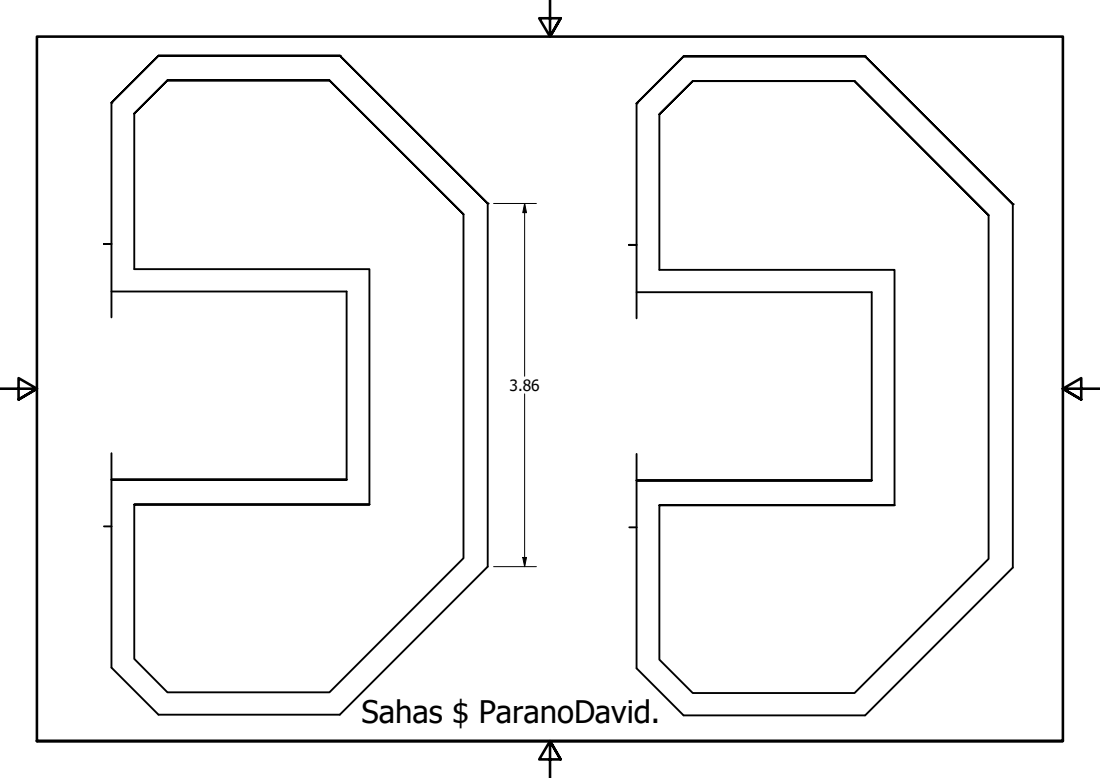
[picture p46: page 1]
Sahas $ ParanoDavid.

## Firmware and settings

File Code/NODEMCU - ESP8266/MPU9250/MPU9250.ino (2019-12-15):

/* 
* This is the code that drives the self balancing mobile transport device. 
* We call it the "<PROJECT_NAME>".
* The code is the backbone of the project and it manages
* the PID loop, the Gyro reading and controlling the VESC all 
* through the NodeMCU which in the future should host a html 
* page for status updates and link it to the Android App.
*/
// sahas

/* add the required Lib's */
#include <Wire.h>
#include <Kalman.h>
#include <PID_v1.h>
#include <SoftwareSerial.h>
#include <VescUart.h>


/* Define the macros for settings.*/
#define RESTRICT_PITCH          // Comment out to restrict roll to ±90deg instead - please read: http://www.freescale.com/files/sensors/doc/app_note/AN3461.pdf
#define SENS_ID 0x71            // Sensor Id for mpu 9250
#define DEBUG_MODE true
#define VESC_BAUD_RATE 115200

double MAX_DUTY_CYCLE = 100.0;      // Max Duty Cycle for the Motor. (% of Max Speed the motor is allowed to go.)

/* Kalman filter constants */
float Q_angle = 0.001; 
float Q_bias = 0.00003;
float R_measure = 0.2;

//float Q_angle = 0.001; 
//float Q_bias = 0.00003;
//float R_measure = 0.2;

/* IMU Data Variables*/
double accX, accY, accZ;
double gyroX, gyroY, gyroZ;
double gyroXangle, gyroYangle;              // Angle calculate using the gyro only
double compAngleX, compAngleY;              // Calculated angle using a complementary filter
double kalAngleX, kalAngleY;                // Calculated angle using a Kalman filter

/* Define variables for PID */
// Specify the links and initial tuning parameters
double Setpoint, Output;
//double Kp=1.5, Ki=0.1, Kd=0.05;
//double Kp=1.0, Ki=0.05, Kd=0.05;
//double Kp=0.0, Ki=0.000, Kd=0.009;
double Kp=4.6, Ki=0.1, Kd=0.0016;
//double Kp=4.6, Ki=0.0, Kd=0.0025;
//double Kp=4.0, Ki=0.1, Kd=0.02;

/* Misc data variables */

uint32_t timer;
uint8_t i2cData[14];                                        // Buffer for I2C data

/* VESC interface */
SoftwareSerial escSoftwareSerial = SoftwareSerial(14, 12);  // ESP8266 (NodeMCU); RX (D5 / GPIO14), TX (D6 / GPIO12)
VescUart vesc;

PID myPID(&kalAngleX, &Output, &Setpoint, Kp, Ki, Kd, REVERSE);

/* Create the Kalman instances */
Kalman kalmanX; 
Kalman kalmanY;

void setup() 
{
  setup_wifi();
  Serial.begin(115200);                      
  escSoftwareSerial.begin(VESC_BAUD_RATE);// begin the serial for VESC. Using softwareSerial lib.
  vesc.setSerialPort(&escSoftwareSerial);
  Wire.begin();                           // begin the I2C port communication
  
/* Set the clock speed for the I2C communication. */
#if ARDUINO >= 157
  Wire.setClock(400000UL);                  // Set I2C frequency to 400kHz
#else
  TWBR = ((F_CPU / 400000UL) - 16) / 2;     // Set I2C frequency to 400kHz if the version 
#endif

/* start the setup */
  setupKalmanFilter();
  setupPID();
  myPID.SetMode(AUTOMATIC);                 // set the PID Mode to Automatic
  myPID.SetOutputLimits(-MAX_DUTY_CYCLE, MAX_DUTY_CYCLE); 
  Serial.println(F("Setup Completed successfully."));
}

void loop()
{
//  Serial.printf("RAM: %d\n", ESP.getFreeHeap());
  
  updateKalmanAnglesXY();                 // Update the kalman-filter predicted angles 
  myPID.Compute();                        // Compute the output from the PID loop
  vesc.setDuty(Output/100.0);
//  vesc.setDuty(3/100.0);
  if (DEBUG_MODE == true)
  {
    Serial.print(kalAngleX, 1); Serial.print(", S.S Error: ");   // X Angle 
    Serial.print(kalAngleX - Setpoint, 1); Serial.print(",");
//    Serial.print(kalAngleY, 1); Serial.print("\t");   // Not necessarily needed
    Serial.print(Output);Serial.print("\n");    // PID controller output
//    Serial.print(F("\n"));
  }
  delay(1);
  loop_wifi();
}

/*
 * function: setupKalmanFilter
 * performs the setup for the kalman filter.
 */
void setupKalmanFilter()
{
  i2cData[0] = 7;                             // Set the sample rate to 1000Hz - 8kHz/(7+1) = 1000Hz
  i2cData[1] = 0x00;                          // Disable FSYNC and set 260 Hz Acc filtering, 256 Hz Gyro filtering, 8 KHz sampling
  i2cData[2] = 0x00;                          // Set Gyro Full Scale Range to ±250deg/s
  i2cData[3] = 0x00;                          // Set Accelerometer Full Scale Range to ±2g
  while (i2cWrite(0x19, i2cData, 4, false)){yield();}  // Write to all four registers at once
  while (i2cWrite(0x6B, 0x01, true)){yield();}         // PLL with X axis gyroscope reference and disable sleep mode
  while (i2cRead(0x75, i2cData, 1)){yield();}

    // Noise filter. 0x06
//  Wire.beginTransmission(0x68);
//  Wire.write(0x1A);                    // write to address 26 of the register
//  Wire.write(0x06);                    // options here are 0x00 which is off, and 0x01, 0x02, 0x03, 0x04, 0x05, 0x06
//  Wire.endTransmission(true);    // 0x06 being the highest filter setting

  // Make sure that the sensor is compatible and connected.
  if (i2cData[0] != SENS_ID) 
  { 
    // Read "WHO_AM_I" register
    if(DEBUG_MODE == true)
    {
      Serial.println(i2cData[0]);
      Serial.print(F("Error reading sensor. Is your sensor hardware: MPU9250?"));
    }
    while (1){yield();} // Do nothing and HALT if the Gyro is not connected/incompatible.
  }
  // Wait a second for sensor to stabilize.
  delay(2000); 

  /* Set kalman and gyro starting angle */
  while (i2cRead(0x3B, i2cData, 6));
  accX = (int16_t)((i2cData[0] << 8) | i2cData[1]);
  accY = (int16_t)((i2cData[2] << 8) | i2cData[3]);
  accZ = (int16_t)((i2cData[4] << 8) | i2cData[5]);

  // Source: http://www.freescale.com/files/sensors/doc/app_note/AN3461.pdf eq. 25 and eq. 26
  // atan2 outputs the value of -π to π (radians) - see http://en.wikipedia.org/wiki/Atan2
  // It is then converted from radians to degrees
#ifdef RESTRICT_PITCH // Eq. 25 and 26
  double roll  = atan2(accY, accZ) * RAD_TO_DEG;
  double pitch = atan(-accX / sqrt(accY * accY + accZ * accZ)) * RAD_TO_DEG;
#else // Eq. 28 and 29
  double roll  = atan(accY / sqrt(accX * accX + accZ * accZ)) * RAD_TO_DEG;
  double pitch = atan2(-accX, accZ) * RAD_TO_DEG;
#endif
  
  // Set starting angle
  kalmanX.setAngle(roll); 
  kalmanY.setAngle(pitch);
  gyroXangle = roll;
  gyroYangle = pitch;
  timer = micros();

  // Set Kalman Filter constants.
  kalmanX.setQangle(Q_angle);     kalmanY.setQangle(Q_angle);    
  kalmanX.setQbias(Q_bias);       kalmanY.setQbias(Q_bias);       
  kalmanX.setRmeasure(R_measure); kalmanY.setRmeasure(R_measure); 
}

void setupPID()
{
  Setpoint = 0.5;           // SETPOINT
  while (!Serial) {yield();}
  myPID.SetSampleTime(30);
}

void updateKalmanAnglesXY() 
{
  /* Update all the values */
  while (i2cRead(0x3B, i2cData, 14)){yield();}
  accX = (int16_t)((i2cData[0] << 8) | i2cData[1]);
  accY = (int16_t)((i2cData[2] << 8) | i2cData[3]);
  accZ = (int16_t)((i2cData[4] << 8) | i2cData[5]);
  gyroX = (int16_t)((i2cData[8] << 8) | i2cData[9]);
  gyroY = (int16_t)((i2cData[10] << 8) | i2cData[11]);
  gyroZ = (int16_t)((i2cData[12] << 8) | i2cData[13]);;

  double dt = (double)(micros() - timer) / 1000000; // Calculate delta time
  timer = micros();

  // Source: http://www.freescale.com/files/sensors/doc/app_note/AN3461.pdf eq. 25 and eq. 26
  // atan2 outputs the value of -π to π (radians) - see http://en.wikipedia.org/wiki/Atan2
  // It is then converted from radians to degrees
#ifdef RESTRICT_PITCH // Eq. 25 and 26
  double roll  = atan2(accY, accZ) * RAD_TO_DEG;
  double pitch = atan(-accX / sqrt(accY * accY + accZ * accZ)) * RAD_TO_DEG; 
  
#else // Eq. 28 and 29
  double roll  = atan(accY / sqrt(accX * accX + accZ * accZ)) * RAD_TO_DEG;
  double pitch = atan2(-accX, accZ) * RAD_TO_DEG;
#endif

  double gyroXrate = gyroX / 131.0; // Convert to deg/s
  double gyroYrate = gyroY / 131.0; // Convert to deg/s

#ifdef RESTRICT_PITCH
  // This fixes the transition problem when the accelerometer angle jumps between -180 and 180 degrees
  if ((roll < -90 && kalAngleX > 90) || (roll > 90 && kalAngleX < -90)) 
  {
    kalmanX.setAngle(roll);
    kalAngleX = roll;
    gyroXangle = roll;
  } 
  else
  {
    kalAngleX = kalmanX.getAngle(roll, gyroXrate, dt);        // Calculate the angle using a Kalman filter
  }
  if (abs(kalAngleX) > 90)
  {
    gyroYrate = -gyroYrate;                                   // Invert rate, so it fits the restriced accelerometer reading
  }
  kalAngleY = kalmanY.getAngle(pitch, gyroYrate, dt);
#else
  // This fixes the transition problem when the accelerometer angle jumps between -180 and 180 degrees
  if ((pitch < -90 && kalAngleY > 90) || (pitch > 90 && kalAngleY < -90)) 
  {
    kalmanY.setAngle(pitch);
    kalAngleY = pitch;
    gyroYangle = pitch;
  } 
  else
    kalAngleY = kalmanY.getAngle(pitch, gyroYrate, dt);       // Calculate the Y angle using a Kalman filter

  if (abs(kalAngleY) > 90)
  {
    gyroXrate = -gyroXrate;                                   // Invert rate, so it fits the restriced accelerometer reading
  }
  kalAngleX = kalmanX.getAngle(roll, gyroXrate, dt);          // Calculate the X angle using a Kalman filter
#endif

//  gyroXangle += gyroXrate * dt;                             // Calculate gyro angle without any filter
//  gyroYangle += gyroYrate * dt;
  gyroXangle += kalmanX.getRate() * dt;                       // Calculate gyro angle using the unbiased rate
  gyroYangle += kalmanY.getRate() * dt;
  /* Reset the gyro angle when it has drifted too much */
  if (gyroXangle < -180 || gyroXangle > 180)                  
  {
    gyroXangle = kalAngleX;
  }
  if (gyroYangle < -180 || gyroYangle > 180)
  {
    gyroYangle = kalAngleY;
  }
}

void  EMERGENCY()
{
  Serial.println("EMERGENCY CALLED");
  while(1)
  {
    vesc.setDuty(0);
    yield();
  }
}

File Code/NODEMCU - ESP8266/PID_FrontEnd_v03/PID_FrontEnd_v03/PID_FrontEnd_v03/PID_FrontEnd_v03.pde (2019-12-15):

/********************************************************
 * Arduino PID Tuning Front-End,  Version 0.3
 * by Brett Beauregard
 * License: Creative-Commons Attribution Share-Alike
 * April 2011
 *
 * This application is designed to interface with an
 * arduino running the PID Library.  From this Control
 * Panel you can observe & adjust PID performance in 
 * real time
 *
 * The ControlP5 library is required to run this sketch.
 * files and install instructions can be found at
 * http://www.sojamo.de/libraries/controlP5/
 * 
 ********************************************************/

import java.nio.ByteBuffer;
import processing.serial.*;
import controlP5.*;

/***********************************************
 * User spcification section
 **********************************************/
int windowWidth = 900;      // set the size of the 
int windowHeight = 600;     // form

float InScaleMin = -15;       // set the Y-Axis Min
float InScaleMax = 15;    // and Max for both
float OutScaleMin = -30;      // the top and 
float OutScaleMax = 30;    // bottom trends


int windowSpan = 150000;    // number of mS into the past you want to display
int refreshRate = 50;      // how often you want the graph to be reDrawn;

//float displayFactor = 1; //display Time as Milliseconds
//float displayFactor = 1000; //display Time as Seconds
float displayFactor = 60000; //display Time as Minutes

String outputFileName = "wheel.txt"; // if you'd like to output data to 
// a file, specify the path here

/***********************************************
 * end user spec
 **********************************************/

int nextRefresh;
int arrayLength = windowSpan / refreshRate+1;
int[] InputData = new int[arrayLength];     //we might not need them this big, but
int[] SetpointData = new int[arrayLength];  // this is worst case
int[] OutputData = new int[arrayLength];


float inputTop = 25;
float inputHeight = (windowHeight-70)*2/3;
float outputTop = inputHeight+50;
float outputHeight = (windowHeight-70)*1/3;

float ioLeft = 150, ioWidth = windowWidth-ioLeft-50;
float ioRight = ioLeft+ioWidth;
float pointWidth= (ioWidth)/float(arrayLength-1);

int vertCount = 10;

int nPoints = 0;

float Input, Setpoint, Output;

boolean madeContact =false;
boolean justSent = true;

Serial myPort;

ControlP5 controlP5;
controlP5.Button AMButton, DRButton;
controlP5.Textlabel AMLabel, AMCurrent, InLabel, 
OutLabel, SPLabel, PLabel, 
ILabel, DLabel,DRLabel, DRCurrent;
controlP5.Textfield SPField, InField, OutField, 
PField, IField, DField;

PrintWriter output;
PFont AxisFont, TitleFont; 

void setup()
{
  frameRate(30);
  size(900 , 600);

  println(Serial.list());                                           // * Initialize Serial
  myPort = new Serial(this, Serial.list()[0], 115200);                //   Communication with
  myPort.bufferUntil(10);                                           //   the Arduino

  controlP5 = new ControlP5(this);                                  // * Initialize the various
  SPField= controlP5.addTextfield("Setpoint",10,100,60,20);         //   Buttons, Labels, and
  InField = controlP5.addTextfield("Input",10,150,60,20);           //   Text Fields we'll be
  OutField = controlP5.addTextfield("Output",10,200,60,20);         //   using
  PField = controlP5.addTextfield("Kp (Proportional)",10,275,60,20);          //
  IField = controlP5.addTextfield("Ki (Integral)",10,325,60,20);          //
  DField = controlP5.addTextfield("Kd (Derivative)",10,375,60,20);          //
  AMButton = controlP5.addButton("Toggle_AM",0.0,10,50,60,20);      //
  AMLabel = controlP5.addTextlabel("AM","Manual",12,72);            //
  AMCurrent = controlP5.addTextlabel("AMCurrent","Manual",80,65);   //
  controlP5.addButton("Send_To_Arduino",0.0,10,475,120,20);         //
  SPLabel=controlP5.addTextlabel("SP","3",80,103);                  //
  InLabel=controlP5.addTextlabel("In","1",80,153);                  //
  OutLabel=controlP5.addTextlabel("Out","2",80,203);                //
  PLabel=controlP5.addTextlabel("P","4",80,278);                    //
  ILabel=controlP5.addTextlabel("I","5",80,328);                    //
  DLabel=controlP5.addTextlabel("D","6",80,378);                    //
  DRButton = controlP5.addButton("Toggle_DR",0.0,10,425,60,20);      //
  DRLabel = controlP5.addTextlabel("DR","Reverse",12,447);            //
  DRCurrent = controlP5.addTextlabel("DRCurrent","Reverse",80,440);   //

  AxisFont = loadFont("axis.vlw");
  TitleFont = loadFont("Titles.vlw");
 
  nextRefresh=millis();
  if (outputFileName!="") output = createWriter(outputFileName);
}

void keyPressed() {
  //output.close(); // Finishes the file
  //exit(); // Stops the program
}

void draw()
{
  background(200);
  drawGraph();
  drawButtonArea();
}
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

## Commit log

2018-11-16 Added VESC-UART functionality.
    VESC can now be controlled by Arduino
    PID needs to be tuned.
2019-12-15 added all the Inventor 2019 CAD files and Arduino Code files.
    [0603 SMD Capacitor.0001.ipt, 0603 SMD Capacitor.ipt, 0603 SMD Resistor.0001.ipt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]
